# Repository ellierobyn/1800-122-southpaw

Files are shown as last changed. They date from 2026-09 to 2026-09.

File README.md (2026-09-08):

# 1800-122 Southpaw Keyboard [WIP]
A bigger than full size keyboard with the arrow keys compressed into the alphas like a 1800 and the number pad on the left (southpaw). Takes inspiration in name and form from the famous IBM Model F122.

1800-122 SP LAYOUT

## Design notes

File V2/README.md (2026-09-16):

# 1800-122 Southpaw V2
This version of the board is the actively in development version using local repos and generally better best practices.

NOTE: The footprints used in the 122-LIB "SW_Hotswap_Kailh_MX_1.00u_**PnP**" & "SW_Hotswap_Kailh_MX_Plated_1.00u_**PnP**" are forked from the official KiCad key switch repo. Positionally they are the same to "SW_Hotswap_Kailh_MX_1.00u" & "SW_Hotswap_Kailh_MX_Plated_1.00u" **EXCEPT** their component origin is located in the same place as JLCPCB's PN C41430893 so the manufacturing files exported are compatible with their Pick and Place machines for automated PCB assembly. The 2 locating pin holes also had their nominal sizes shrunk by .001" to accommodate JLCPCB's capabilities.

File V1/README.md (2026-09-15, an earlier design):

# NOTICE: DEPRECATED

This version of the PCB utilized ai03's deprecated MX Keyswitch Libraries, a random RP2040 lib and a random W25Q128JVSIQ lib. I don't recommend using this PCB as a finished project but may be a helpful reference. This PCB was never manufactured so there are also probably DRC errors.

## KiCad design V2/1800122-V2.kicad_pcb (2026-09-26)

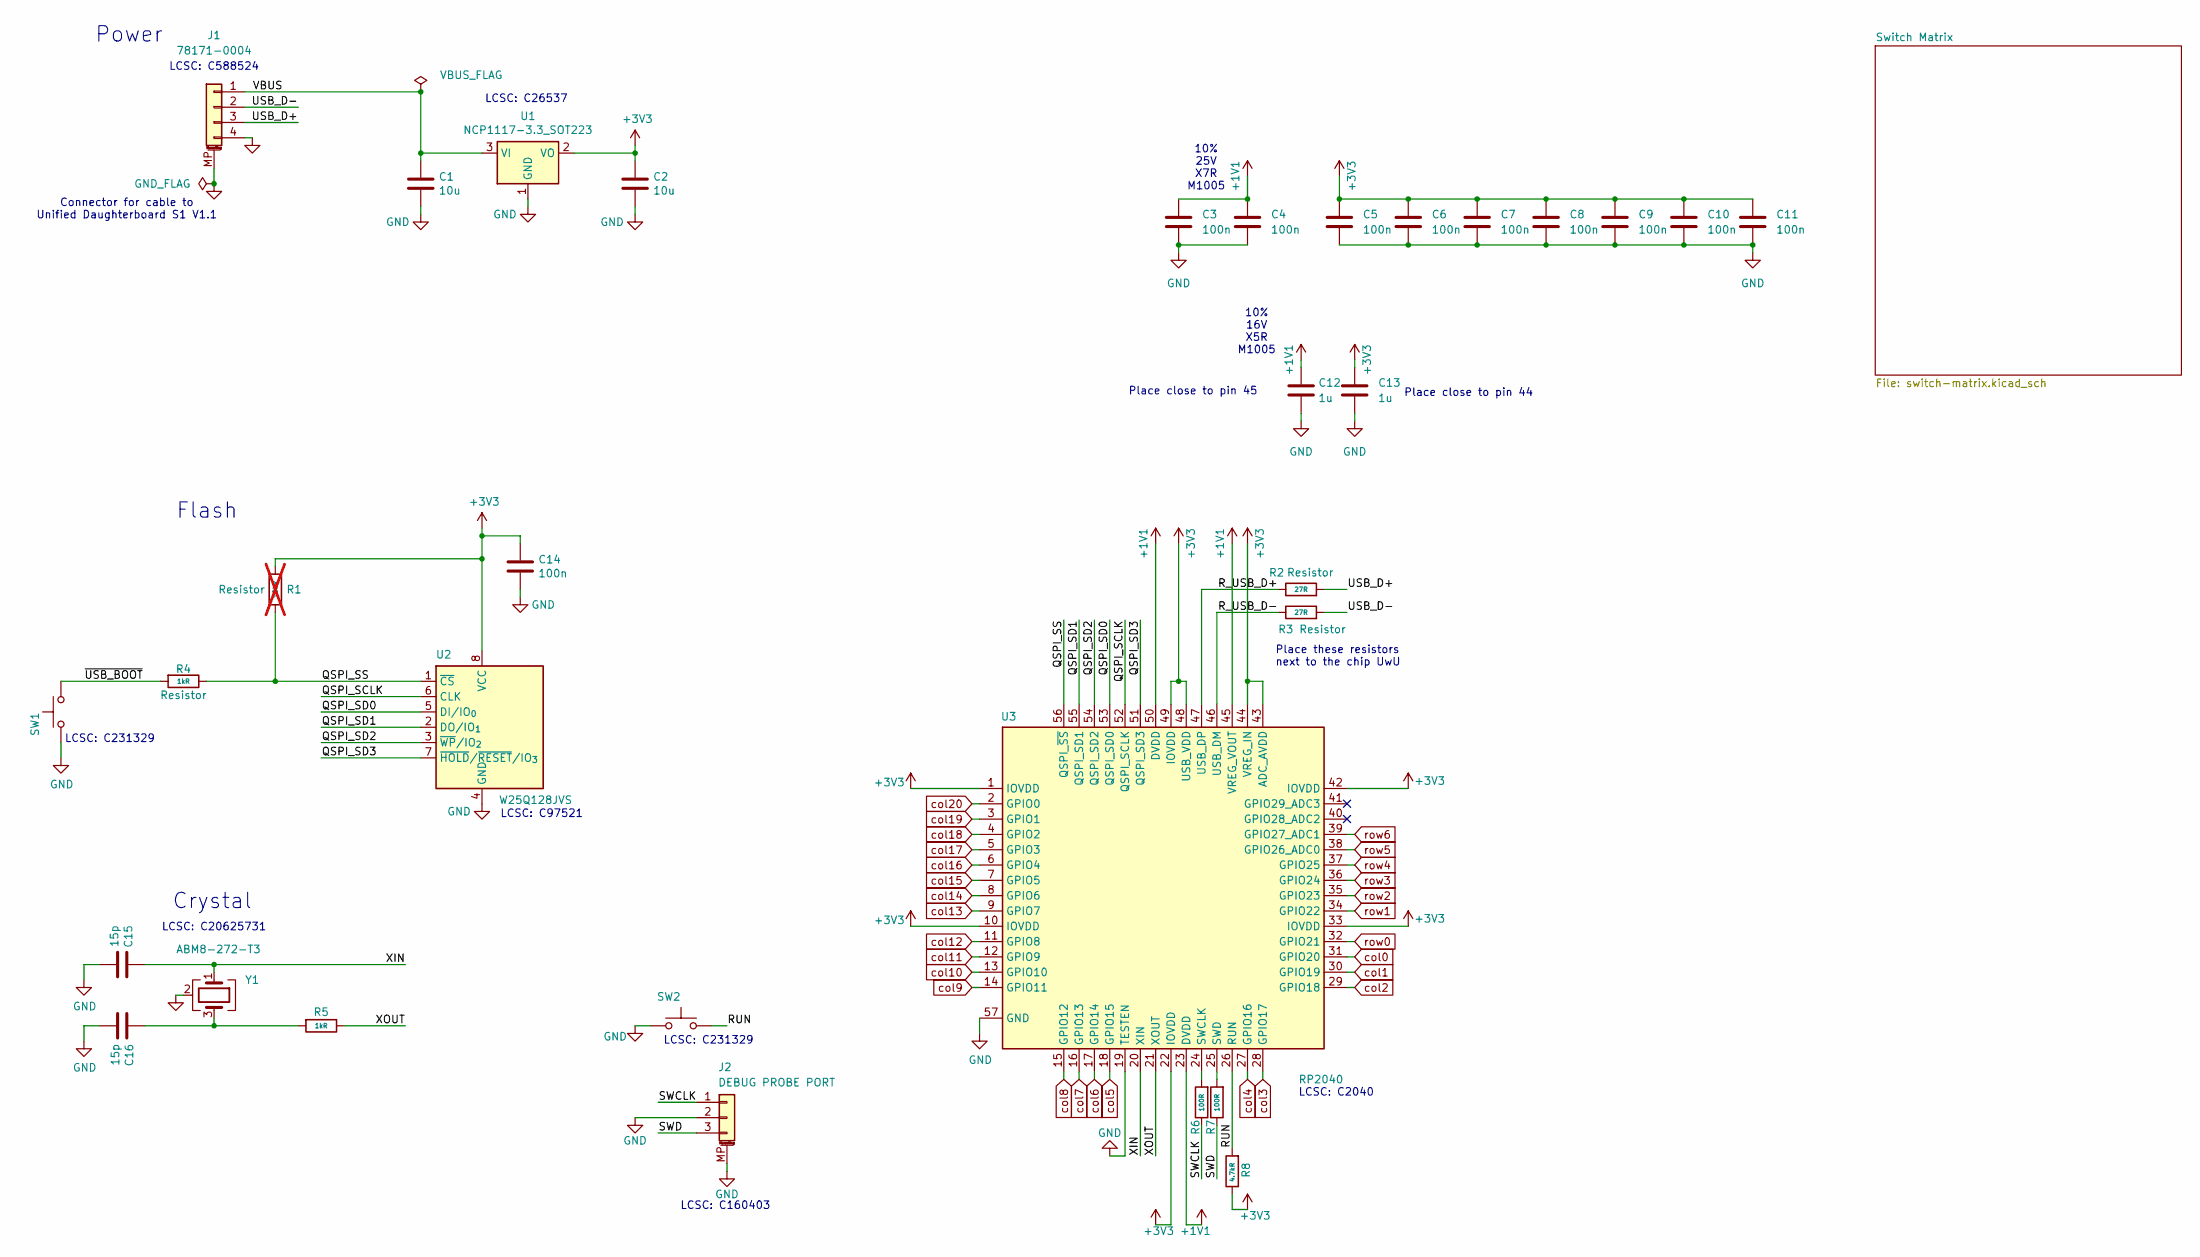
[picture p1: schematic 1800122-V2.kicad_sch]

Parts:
C1, C2: 10u; C_0402_1005Metric-JLCSILK
C3, C4, C5, C6, C7, C8, C9, C10, C11, C14: 100n; C_0402_1005Metric-JLCSILK
C12, C13: 1u; C_0402_1005Metric-JLCSILK
C15, C16: 15p; C_0402_1005Metric-JLCSILK
J1: 78171-0004; PicoEZMate-Reinforced-Lite; Manufacturer Part Number 78171-0004; LCSC Part Number C588524
J2: DEBUG PROBE PORT; JST_SH_SM03B-SRSS-TB_1x03-1MP_P1.00mm_Horizontal; LCSC Part Number C160403
R1: 10kR; R_0402_1005Metric-JLCSILK; not fitted
R2, R3: 27R; R_0402_1005Metric-JLCSILK
R4, R5: 1kR; R_0402_1005Metric-JLCSILK
R6, R7: 100R; R_0402_1005Metric-JLCSILK
R8: 4.7kR; R_0402_1005Metric-JLCSILK
SW1: BOOTSEL; SW_SPST_B3U-1000P; LCSC Part Number C231329
SW2: RESET; SW_SPST_B3U-1000P; LCSC Part Number C231329
U1: NCP1117-3.3_SOT223; SOT-223-3_TabPin2; LCSC Part Number C26537
U2: W25Q128JVS; SOIC-8_5.3x5.3mm_P1.27mm; LCSC Part Number C97521
U3: RP2040; part_uid RP-01EKHS-ZTKTEH; LCSC Part Number C2040
Y1: ABM8-272-T3; Crystal_SMD_3225-4Pin_3.2x2.5mm; LCSC Part Number C20625731

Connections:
+1V1: C3.1, C4.1, C12.1, U3.23 (DVDD), U3.45 (VREG_VOUT), U3.50 (DVDD)
+3V3: C2.1, C5.1, C6.1, C7.1, C8.1, C9.1, C10.1, C11.1, C13.1, C14.1, R1.1, R8.1, U1.2 (VO), U2.8 (VCC), U3.1 (IOVDD), U3.10 (IOVDD), U3.22 (IOVDD), U3.33 (IOVDD), U3.42 (IOVDD), U3.43 (ADC_AVDD), U3.44 (VREG_IN), U3.48 (USB_VDD), U3.49 (IOVDD)
/QSPI_SCLK: U2.6 (CLK), U3.52 (QSPI_SCLK)
/QSPI_SD0: U2.5 (DI/IO_{0}), U3.53 (QSPI_SD0)
/QSPI_SD1: U2.2 (DO/IO_{1}), U3.55 (QSPI_SD1)
/QSPI_SD2: U2.3 (~WP/IO_{2}), U3.54 (QSPI_SD2)
/QSPI_SD3: U2.7 (~HOLD/~RESET/IO_{3}), U3.51 (QSPI_SD3)
/QSPI_SS: R1.2, R4.1, U2.1 (~CS), U3.56 (QSPI_~SS)
/RUN: R8.2, SW2.2, U3.26 (RUN)
/R_USB_D+: R2.1, U3.47 (USB_DP)
/R_USB_D-: R3.1, U3.46 (USB_DM)
/SWCLK: J2.1, R6.1
/SWD: J2.3, R7.1
/USB_D+: J1.3, R2.2
/USB_D-: J1.2, R3.2
/VBUS: C1.1, J1.1, U1.3 (VI)
/XIN: C15.1, U3.20 (XIN), Y1.1
/XOUT: R5.1, U3.21 (XOUT)
/~USB_BOOT: R4.2, SW1.2
GND: C1.2, C2.2, C3.2, C4.2, C5.2, C6.2, C7.2, C8.2, C9.2, C10.2, C11.2, C12.2, C13.2, C14.2, C15.2, C16.2, J1.4, J1.MP (MountPin), J2.2, J2.MP (MountPin), SW1.1, SW2.1, U1.1 (GND), U2.4 (GND), U3.19 (TESTEN), U3.57 (GND), Y1.2 (G), Y1.4 (G)
unnamed: C16.1, R5.2, Y1.3
unnamed: R6.2, U3.24 (SWCLK)
unnamed: R7.2, U3.25 (SWD)
col0: U3.31 (GPIO20); also elsewhere on the board
col1: U3.30 (GPIO19); also elsewhere on the board
col2: U3.29 (GPIO18); also elsewhere on the board
col3: U3.28 (GPIO17); also elsewhere on the board
col4: U3.27 (GPIO16); also elsewhere on the board
col5: U3.18 (GPIO15); also elsewhere on the board
col6: U3.17 (GPIO14); also elsewhere on the board
col7: U3.16 (GPIO13); also elsewhere on the board
col8: U3.15 (GPIO12); also elsewhere on the board
col9: U3.14 (GPIO11); also elsewhere on the board
col10: U3.13 (GPIO10); also elsewhere on the board
col11: U3.12 (GPIO9); also elsewhere on the board
col12: U3.11 (GPIO8); also elsewhere on the board
col13: U3.9 (GPIO7); also elsewhere on the board
col14: U3.8 (GPIO6); also elsewhere on the board
col15: U3.7 (GPIO5); also elsewhere on the board
col16: U3.6 (GPIO4); also elsewhere on the board
col17: U3.5 (GPIO3); also elsewhere on the board
col18: U3.4 (GPIO2); also elsewhere on the board
col19: U3.3 (GPIO1); also elsewhere on the board
col20: U3.2 (GPIO0); also elsewhere on the board
row0: U3.32 (GPIO21); also elsewhere on the board
row1: U3.34 (GPIO22); also elsewhere on the board
row2: U3.35 (GPIO23); also elsewhere on the board
row3: U3.36 (GPIO24); also elsewhere on the board
row4: U3.37 (GPIO25); also elsewhere on the board
row5: U3.38 (GPIO26_ADC0); also elsewhere on the board
row6: U3.39 (GPIO27_ADC1); also elsewhere on the board

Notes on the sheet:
LCSC: C2040
LCSC: C20625731
LCSC: C26537
Power
Crystal
LCSC: C97521
Place close to pin 45
LCSC: C231329
Connector for cable to Unified Daughterboard S1 V1.1
10% 16V X5R M1005
LCSC: C160403
10% 25V X7R M1005
Place close to pin 44
LCSC: C588524
Place these resistors next to the chip UwU
Flash

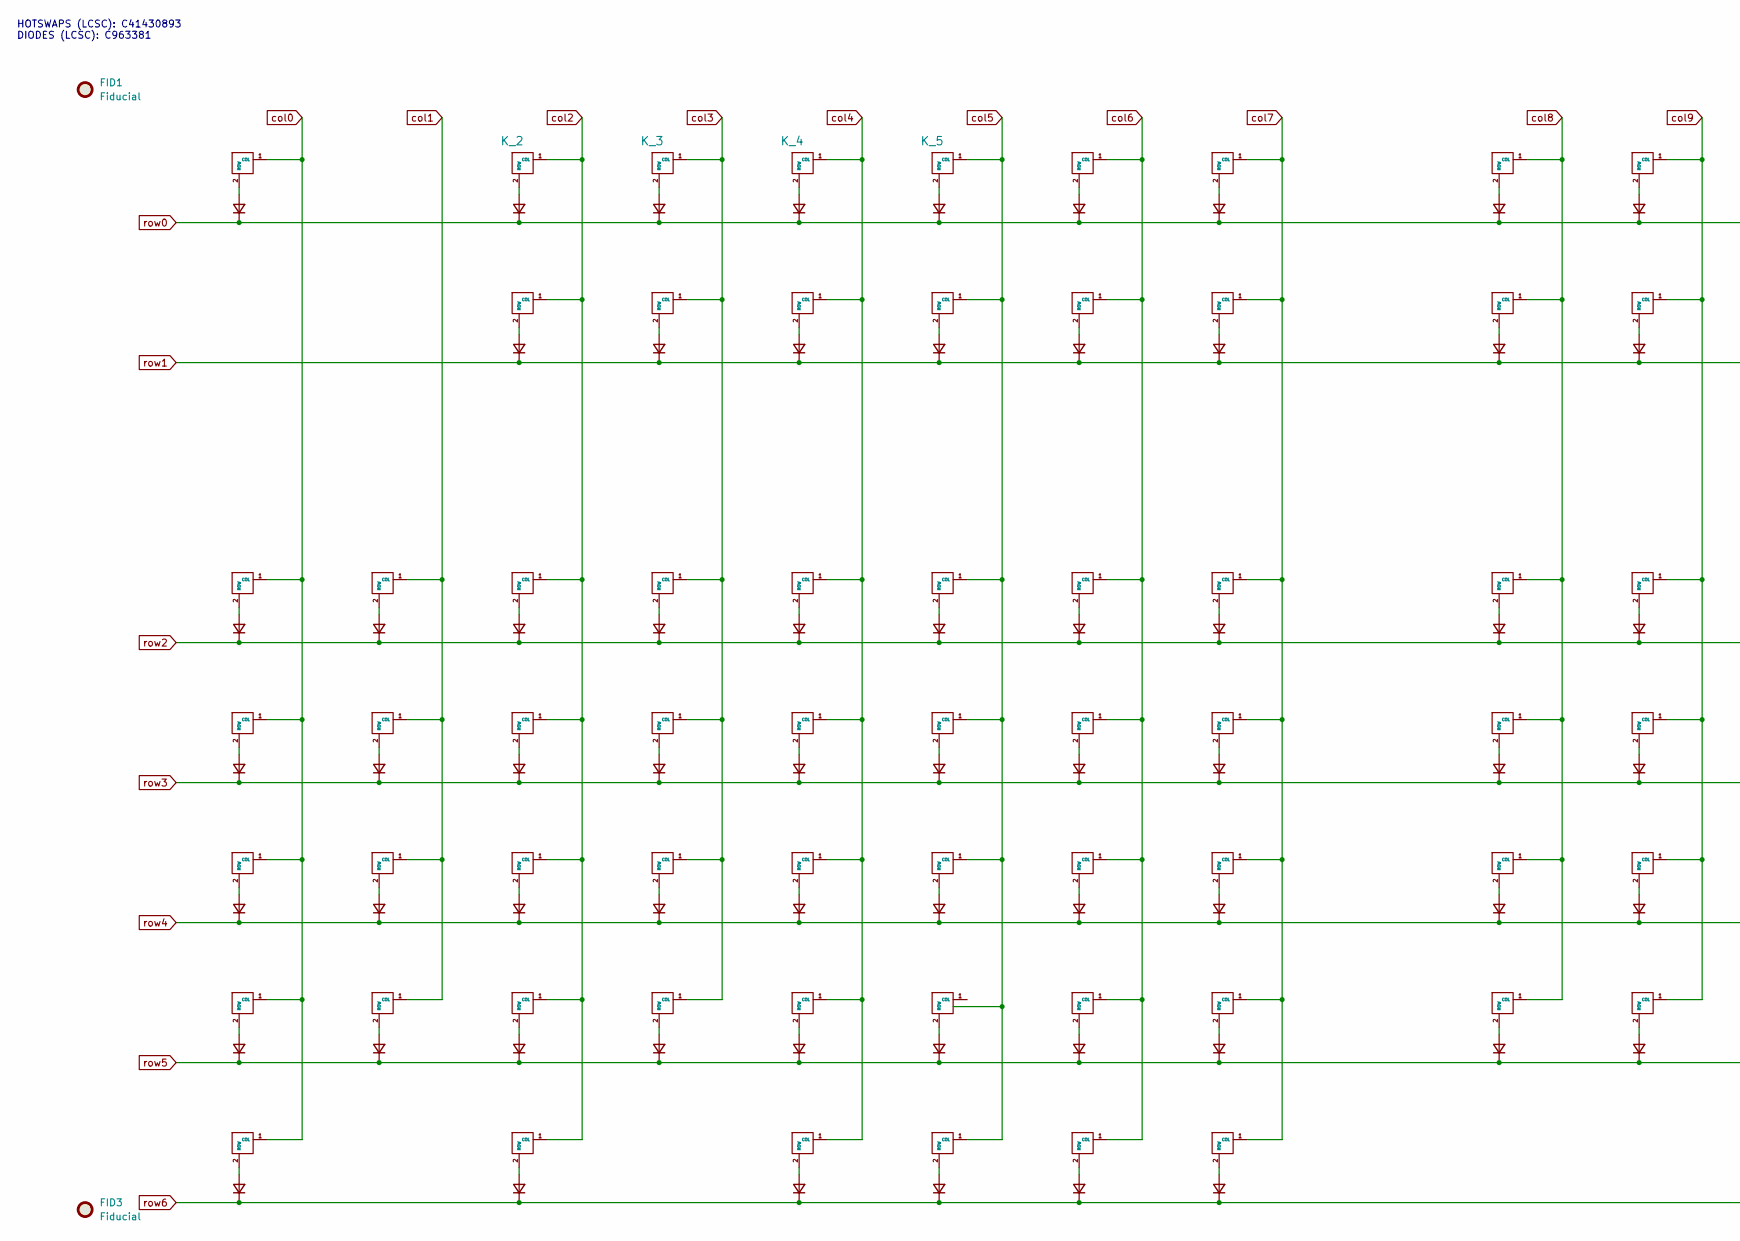
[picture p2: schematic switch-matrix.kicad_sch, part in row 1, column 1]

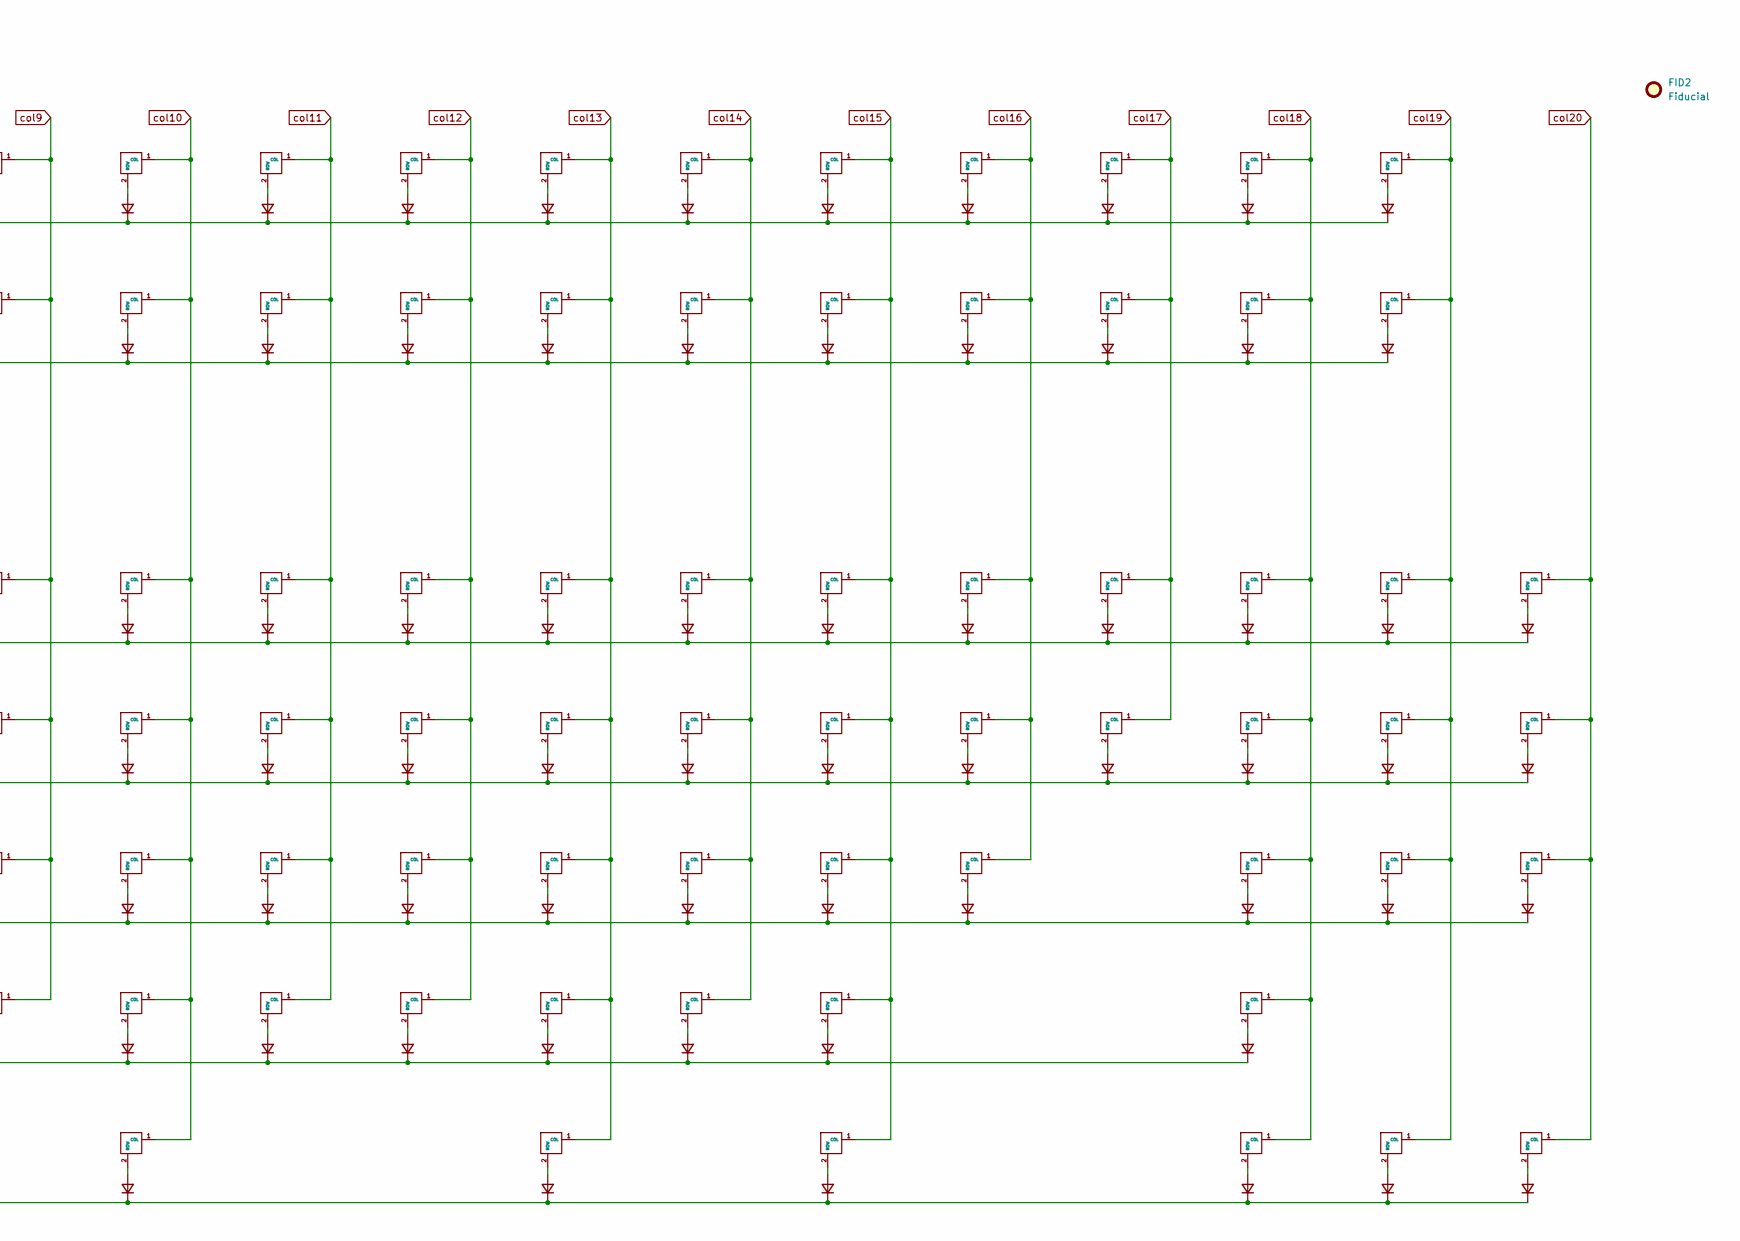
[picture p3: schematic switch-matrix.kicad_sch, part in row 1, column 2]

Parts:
D_1, D_2, D_3, D_4, D_5, D_6, D_7, D_8, D_9, D_10, D_11, D_12, D_13, D_14, D_15, D_16, D_17, D_18, D_19, D_20, D_21, D_22, D_23, D_24, D_25, D_26, D_27, D_28, D_29, D_30, D_31, D_32, D_33, D_34, D_35, D_36, D_37, D_38, D_39, D_40, D_41, D_42, D_43, D_44, D_45, D_46, D_47, D_48, D_49, D_50, D_51, D_52, D_53, D_54, D_55, D_56, D_57, D_58, D_59, D_60, D_61, D_62, D_63, D_64, D_65, D_66, D_67, D_68, D_69, D_70, D_71, D_72, D_73, D_74, D_75, D_76, D_77, D_78, D_79, D_80, D_81, D_82, D_83, D_84, D_85, D_86, D_87, D_88, D_89, D_90, D_91, D_92, D_93, D_94, D_95, D_96, D_97, D_98, D_99, D_100, D_101, D_102, D_103, D_104, D_105, D_106, D_107, D_108, D_109, D_110, D_111, D_112, D_113, D_114, D_115, D_116, D_117, D_118, D_119, D_120, D_121, D_122, D_123, D_124, D_125, D_126, D_127, D_128: D; D_SOD-123; LCSC Part Number C963381
FID1, FID2, FID3: Fiducial; Fiducial_1mm_Mask2mm
K_1, K_2, K_3, K_4, K_5, K_6, K_7, K_8, K_9, K_10, K_11, K_12, K_13, K_14, K_15, K_16, K_17, K_18, K_19, K_20, K_21, K_22, K_23, K_24, K_25, K_26, K_27, K_28, K_29, K_30, K_31, K_32, K_33, K_34, K_35, K_36, K_37, K_38, K_39, K_40, K_41, K_42, K_43, K_44, K_45, K_46, K_47, K_48, K_49, K_50, K_51, K_52, K_53, K_54, K_55, K_56, K_57, K_58, K_59, K_60, K_61, K_62, K_63, K_64, K_65, K_66, K_67, K_68, K_69, K_70, K_71, K_72, K_73, K_74, K_75, K_76, K_77, K_78, K_79, K_80, K_81, K_82, K_83, K_84, K_85, K_86, K_87, K_88, K_89, K_90, K_91, K_92, K_93, K_94, K_95, K_96, K_97, K_98, K_99, K_100, K_101, K_102, K_103, K_104, K_105, K_106, K_107, K_108, K_109, K_110, K_111, K_112, K_113, K_114, K_115, K_116, K_117, K_118, K_119, K_120, K_121, K_122, K_123, K_124, K_125, K_126, K_127, K_128: KEYSW; SW_Hotswap_Kailh_MX_Plated_1.00u_PnP; LCSC Part Number C41430893

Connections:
unnamed: D_1.2 (A), K_1.2 (ROW)
unnamed: D_2.2 (A), K_2.2 (ROW)
unnamed: D_3.2 (A), K_3.2 (ROW)
unnamed: D_4.2 (A), K_4.2 (ROW)
unnamed: D_5.2 (A), K_5.2 (ROW)
unnamed: D_6.2 (A), K_6.2 (ROW)
unnamed: D_7.2 (A), K_7.2 (ROW)
unnamed: D_8.2 (A), K_8.2 (ROW)
unnamed: D_9.2 (A), K_9.2 (ROW)
unnamed: D_10.2 (A), K_10.2 (ROW)
unnamed: D_11.2 (A), K_11.2 (ROW)
unnamed: D_12.2 (A), K_12.2 (ROW)
unnamed: D_13.2 (A), K_13.2 (ROW)
unnamed: D_14.2 (A), K_14.2 (ROW)
unnamed: D_15.2 (A), K_15.2 (ROW)
unnamed: D_16.2 (A), K_16.2 (ROW)
unnamed: D_17.2 (A), K_17.2 (ROW)
unnamed: D_18.2 (A), K_18.2 (ROW)
unnamed: D_19.2 (A), K_19.2 (ROW)
unnamed: D_20.2 (A), K_20.2 (ROW)
unnamed: D_21.2 (A), K_21.2 (ROW)
unnamed: D_22.2 (A), K_22.2 (ROW)
unnamed: D_23.2 (A), K_23.2 (ROW)
unnamed: D_24.2 (A), K_24.2 (ROW)
unnamed: D_25.2 (A), K_25.2 (ROW)
unnamed: D_26.2 (A), K_26.2 (ROW)
unnamed: D_27.2 (A), K_27.2 (ROW)
unnamed: D_28.2 (A), K_28.2 (ROW)
unnamed: D_29.2 (A), K_29.2 (ROW)
unnamed: D_30.2 (A), K_30.2 (ROW)
unnamed: D_31.2 (A), K_31.2 (ROW)
unnamed: D_32.2 (A), K_32.2 (ROW)
unnamed: D_33.2 (A), K_33.2 (ROW)
unnamed: D_34.2 (A), K_34.2 (ROW)
unnamed: D_35.2 (A), K_35.2 (ROW)
unnamed: D_36.2 (A), K_36.2 (ROW)
unnamed: D_37.2 (A), K_37.2 (ROW)
unnamed: D_38.2 (A), K_38.2 (ROW)
unnamed: D_39.2 (A), K_39.2 (ROW)
unnamed: D_40.2 (A), K_40.2 (ROW)
unnamed: D_41.2 (A), K_41.2 (ROW)
unnamed: D_42.2 (A), K_42.2 (ROW)
unnamed: D_43.2 (A), K_43.2 (ROW)
unnamed: D_44.2 (A), K_44.2 (ROW)
unnamed: D_45.2 (A), K_45.2 (ROW)
unnamed: D_46.2 (A), K_46.2 (ROW)
unnamed: D_47.2 (A), K_47.2 (ROW)
unnamed: D_48.2 (A), K_48.2 (ROW)
unnamed: D_49.2 (A), K_49.2 (ROW)
unnamed: D_50.2 (A), K_50.2 (ROW)
unnamed: D_51.2 (A), K_51.2 (ROW)
unnamed: D_52.2 (A), K_52.2 (ROW)
unnamed: D_53.2 (A), K_53.2 (ROW)
unnamed: D_54.2 (A), K_54.2 (ROW)
unnamed: D_55.2 (A), K_55.2 (ROW)
unnamed: D_56.2 (A), K_56.2 (ROW)
unnamed: D_57.2 (A), K_57.2 (ROW)
unnamed: D_58.2 (A), K_58.2 (ROW)
unnamed: D_59.2 (A), K_59.2 (ROW)
unnamed: D_60.2 (A), K_60.2 (ROW)
unnamed: D_61.2 (A), K_61.2 (ROW)
unnamed: D_62.2 (A), K_62.2 (ROW)
unnamed: D_63.2 (A), K_63.2 (ROW)
unnamed: D_64.2 (A), K_64.2 (ROW)
unnamed: D_65.2 (A), K_65.2 (ROW)
unnamed: D_66.2 (A), K_66.2 (ROW)
unnamed: D_67.2 (A), K_67.2 (ROW)
unnamed: D_68.2 (A), K_68.2 (ROW)
unnamed: D_69.2 (A), K_69.2 (ROW)
unnamed: D_70.2 (A), K_70.2 (ROW)
unnamed: D_71.2 (A), K_71.2 (ROW)
unnamed: D_72.2 (A), K_72.2 (ROW)
unnamed: D_73.2 (A), K_73.2 (ROW)
unnamed: D_74.2 (A), K_74.2 (ROW)
unnamed: D_75.2 (A), K_75.2 (ROW)
unnamed: D_76.2 (A), K_76.2 (ROW)
unnamed: D_77.2 (A), K_77.2 (ROW)
unnamed: D_78.2 (A), K_78.2 (ROW)
unnamed: D_79.2 (A), K_79.2 (ROW)
unnamed: D_80.2 (A), K_80.2 (ROW)
unnamed: D_81.2 (A), K_81.2 (ROW)
unnamed: D_82.2 (A), K_82.2 (ROW)
unnamed: D_83.2 (A), K_83.2 (ROW)
unnamed: D_84.2 (A), K_84.2 (ROW)
unnamed: D_85.2 (A), K_85.2 (ROW)
unnamed: D_86.2 (A), K_86.2 (ROW)
unnamed: D_87.2 (A), K_87.2 (ROW)
unnamed: D_88.2 (A), K_88.2 (ROW)
unnamed: D_89.2 (A), K_89.2 (ROW)
unnamed: D_90.2 (A), K_90.2 (ROW)
unnamed: D_91.2 (A), K_91.2 (ROW)
unnamed: D_92.2 (A), K_92.2 (ROW)
unnamed: D_93.2 (A), K_93.2 (ROW)
unnamed: D_94.2 (A), K_94.2 (ROW)
unnamed: D_95.2 (A), K_95.2 (ROW)
unnamed: D_96.2 (A), K_96.2 (ROW)
unnamed: D_97.2 (A), K_97.2 (ROW)
unnamed: D_98.2 (A), K_98.2 (ROW)
unnamed: D_99.2 (A), K_99.2 (ROW)
unnamed: D_100.2 (A), K_100.2 (ROW)
unnamed: D_101.2 (A), K_101.2 (ROW)
unnamed: D_102.2 (A), K_102.2 (ROW)
unnamed: D_103.2 (A), K_103.2 (ROW)
unnamed: D_104.2 (A), K_104.2 (ROW)
unnamed: D_105.2 (A), K_105.2 (ROW_2)
unnamed: D_106.2 (A), K_106.2 (ROW)
unnamed: D_107.2 (A), K_107.2 (ROW)
unnamed: D_108.2 (A), K_108.2 (ROW)
unnamed: D_109.2 (A), K_109.2 (ROW)
unnamed: D_110.2 (A), K_110.2 (ROW)
unnamed: D_111.2 (A), K_111.2 (ROW)
unnamed: D_112.2 (A), K_112.2 (ROW)
unnamed: D_113.2 (A), K_113.2 (ROW)
unnamed: D_114.2 (A), K_114.2 (ROW)
unnamed: D_115.2 (A), K_115.2 (ROW)
unnamed: D_116.2 (A), K_116.2 (ROW)
unnamed: D_117.2 (A), K_117.2 (ROW)
unnamed: D_118.2 (A), K_118.2 (ROW)
unnamed: D_119.2 (A), K_119.2 (ROW)
unnamed: D_120.2 (A), K_120.2 (ROW)
unnamed: D_121.2 (A), K_121.2 (ROW)
unnamed: D_122.2 (A), K_122.2 (ROW)
unnamed: D_123.2 (A), K_123.2 (ROW)
unnamed: D_124.2 (A), K_124.2 (ROW)
unnamed: D_125.2 (A), K_125.2 (ROW)
unnamed: D_126.2 (A), K_126.2 (ROW)
unnamed: D_127.2 (A), K_127.2 (ROW)
unnamed: D_128.2 (A), K_128.2 (ROW)
col0: K_1.1 (COL), K_38.1 (COL), K_59.1 (COL), K_80.1 (COL), K_100.1 (COL), K_117.1 (COL); also elsewhere on the board
col1: K_39.1 (COL), K_60.1 (COL), K_81.1 (COL), K_101.1 (COL); also elsewhere on the board
col2: K_2.1 (COL), K_20.1 (COL), K_40.1 (COL), K_61.1 (COL), K_82.1 (COL), K_102.1 (COL), K_118.1 (COL); also elsewhere on the board
col3: K_3.1 (COL), K_21.1 (COL), K_41.1 (COL), K_62.1 (COL), K_83.1 (COL), K_103.1 (COL); also elsewhere on the board
col4: K_4.1 (COL), K_22.1 (COL), K_42.1 (COL), K_63.1 (COL), K_84.1 (COL), K_104.1 (COL), K_119.1 (COL); also elsewhere on the board
col5: K_5.1 (COL), K_23.1 (COL), K_43.1 (COL), K_64.1 (COL), K_85.1 (COL), K_120.1 (COL); also elsewhere on the board
col6: K_6.1 (COL), K_24.1 (COL), K_44.1 (COL), K_65.1 (COL), K_86.1 (COL), K_106.1 (COL), K_121.1 (COL); also elsewhere on the board
col7: K_7.1 (COL), K_25.1 (COL), K_45.1 (COL), K_66.1 (COL), K_87.1 (COL), K_107.1 (COL), K_122.1 (COL); also elsewhere on the board
col8: K_8.1 (COL), K_26.1 (COL), K_46.1 (COL), K_67.1 (COL), K_88.1 (COL), K_108.1 (COL); also elsewhere on the board
col9: K_9.1 (COL), K_27.1 (COL), K_47.1 (COL), K_68.1 (COL), K_89.1 (COL), K_109.1 (COL); also elsewhere on the board
col10: K_10.1 (COL), K_28.1 (COL), K_48.1 (COL), K_69.1 (COL), K_90.1 (COL), K_110.1 (COL), K_123.1 (COL); also elsewhere on the board
col11: K_11.1 (COL), K_29.1 (COL), K_49.1 (COL), K_70.1 (COL), K_91.1 (COL), K_111.1 (COL); also elsewhere on the board
col12: K_12.1 (COL), K_30.1 (COL), K_50.1 (COL), K_71.1 (COL), K_92.1 (COL), K_112.1 (COL); also elsewhere on the board
col13: K_13.1 (COL), K_31.1 (COL), K_51.1 (COL), K_72.1 (COL), K_93.1 (COL), K_113.1 (COL), K_124.1 (COL); also elsewhere on the board
col14: K_14.1 (COL), K_32.1 (COL), K_52.1 (COL), K_73.1 (COL), K_94.1 (COL), K_114.1 (COL); also elsewhere on the board
col15: K_15.1 (COL), K_33.1 (COL), K_53.1 (COL), K_74.1 (COL), K_95.1 (COL), K_115.1 (COL), K_125.1 (COL); also elsewhere on the board
col16: K_16.1 (COL), K_34.1 (COL), K_54.1 (COL), K_75.1 (COL), K_96.1 (COL); also elsewhere on the board
col17: K_17.1 (COL), K_35.1 (COL), K_55.1 (COL), K_76.1 (COL); also elsewhere on the board
col18: K_18.1 (COL), K_36.1 (COL), K_56.1 (COL), K_77.1 (COL), K_97.1 (COL), K_116.1 (COL), K_126.1 (COL); also elsewhere on the board
col19: K_19.1 (COL), K_37.1 (COL), K_57.1 (COL), K_78.1 (COL), K_98.1 (COL), K_127.1 (COL); also elsewhere on the board
col20: K_58.1 (COL), K_79.1 (COL), K_99.1 (COL), K_128.1 (COL); also elsewhere on the board
row0: D_1.1 (K), D_2.1 (K), D_3.1 (K), D_4.1 (K), D_5.1 (K), D_6.1 (K), D_7.1 (K), D_8.1 (K), D_9.1 (K), D_10.1 (K), D_11.1 (K), D_12.1 (K), D_13.1 (K), D_14.1 (K), D_15.1 (K), D_16.1 (K), D_17.1 (K), D_18.1 (K), D_19.1 (K); also elsewhere on the board
row1: D_20.1 (K), D_21.1 (K), D_22.1 (K), D_23.1 (K), D_24.1 (K), D_25.1 (K), D_26.1 (K), D_27.1 (K), D_28.1 (K), D_29.1 (K), D_30.1 (K), D_31.1 (K), D_32.1 (K), D_33.1 (K), D_34.1 (K), D_35.1 (K), D_36.1 (K), D_37.1 (K); also elsewhere on the board
row2: D_38.1 (K), D_39.1 (K), D_40.1 (K), D_41.1 (K), D_42.1 (K), D_43.1 (K), D_44.1 (K), D_45.1 (K), D_46.1 (K), D_47.1 (K), D_48.1 (K), D_49.1 (K), D_50.1 (K), D_51.1 (K), D_52.1 (K), D_53.1 (K), D_54.1 (K), D_55.1 (K), D_56.1 (K), D_57.1 (K), D_58.1 (K); also elsewhere on the board
row3: D_59.1 (K), D_60.1 (K), D_61.1 (K), D_62.1 (K), D_63.1 (K), D_64.1 (K), D_65.1 (K), D_66.1 (K), D_67.1 (K), D_68.1 (K), D_69.1 (K), D_70.1 (K), D_71.1 (K), D_72.1 (K), D_73.1 (K), D_74.1 (K), D_75.1 (K), D_76.1 (K), D_77.1 (K), D_78.1 (K), D_79.1 (K); also elsewhere on the board
row4: D_80.1 (K), D_81.1 (K), D_82.1 (K), D_83.1 (K), D_84.1 (K), D_85.1 (K), D_86.1 (K), D_87.1 (K), D_88.1 (K), D_89.1 (K), D_90.1 (K), D_91.1 (K), D_92.1 (K), D_93.1 (K), D_94.1 (K), D_95.1 (K), D_96.1 (K), D_97.1 (K), D_98.1 (K), D_99.1 (K); also elsewhere on the board
row5: D_100.1 (K), D_101.1 (K), D_102.1 (K), D_103.1 (K), D_104.1 (K), D_105.1 (K), D_106.1 (K), D_107.1 (K), D_108.1 (K), D_109.1 (K), D_110.1 (K), D_111.1 (K), D_112.1 (K), D_113.1 (K), D_114.1 (K), D_115.1 (K), D_116.1 (K); also elsewhere on the board
row6: D_117.1 (K), D_118.1 (K), D_119.1 (K), D_120.1 (K), D_121.1 (K), D_122.1 (K), D_123.1 (K), D_124.1 (K), D_125.1 (K), D_126.1 (K), D_127.1 (K), D_128.1 (K); also elsewhere on the board

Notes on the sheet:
HOTSWAPS (LCSC): C41430893 DIODES (LCSC): C963381

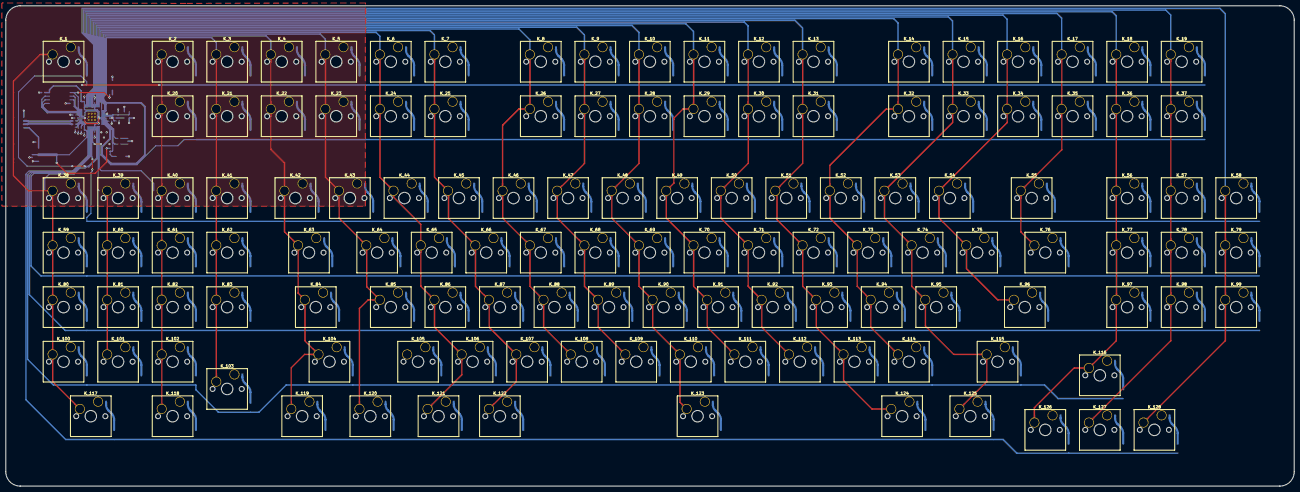
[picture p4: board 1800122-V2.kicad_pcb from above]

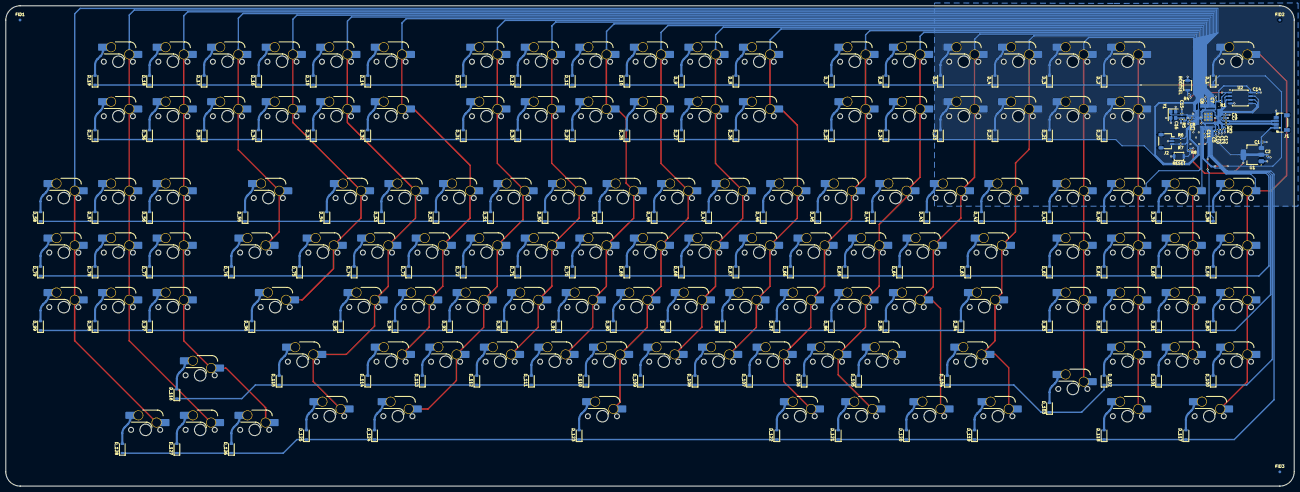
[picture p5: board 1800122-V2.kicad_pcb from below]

Board: 2 copper layers, 450.0 x 167.8 mm, 291 parts (163 on the bottom side), 179 nets.

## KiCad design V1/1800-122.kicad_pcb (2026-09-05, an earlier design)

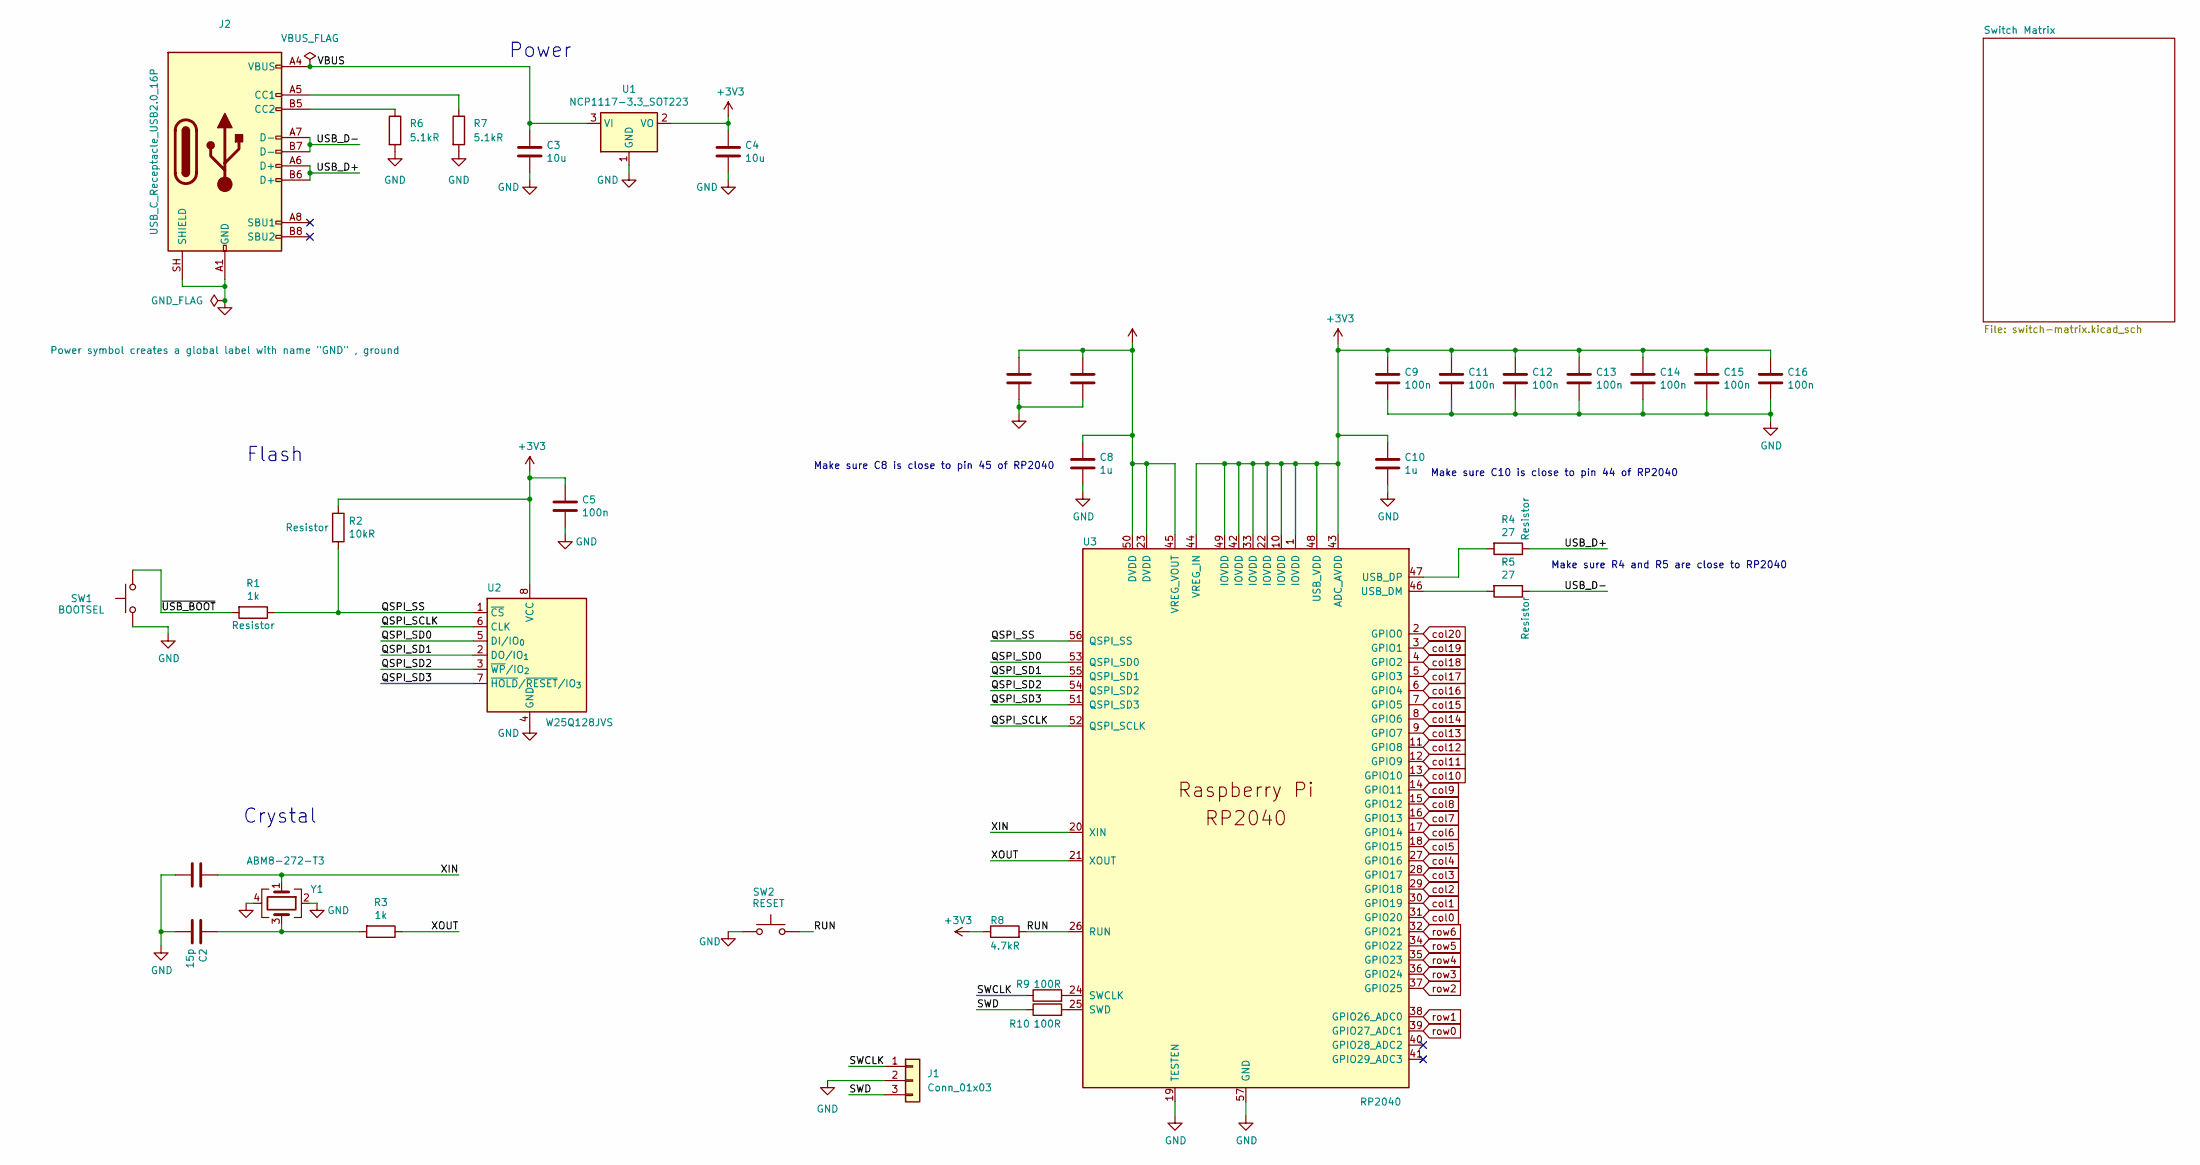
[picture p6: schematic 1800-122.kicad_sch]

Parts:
C1, C2: 15p; C_0402_1005Metric_Pad0.74x0.62mm_HandSolder
C3, C4: 10u; C_0402_1005Metric_Pad0.74x0.62mm_HandSolder
C5, C6, C7, C9, C11, C12, C13, C14, C15, C16: 100n; C_0402_1005Metric_Pad0.74x0.62mm_HandSolder
C8, C10: 1u; C_0402_1005Metric_Pad0.74x0.62mm_HandSolder
J1: Conn_01x03; JST_SH_SM03B-SRSS-TB_1x03-1MP_P1.00mm_Horizontal
J2: USB_C_Receptacle_USB2.0_16P; USB_C_Receptacle_GCT_USB4105-xx-A_16P_TopMnt_Horizontal
R1, R3: 1k; R_0402_1005Metric_Pad0.72x0.64mm_HandSolder
R2: 10kR; R_0402_1005Metric_Pad0.72x0.64mm_HandSolder
R4, R5: 27; R_0402_1005Metric_Pad0.72x0.64mm_HandSolder
R6, R7: 5.1kR; R_0402_1005Metric_Pad0.72x0.64mm_HandSolder
R8: 4.7kR; R_0402_1005Metric_Pad0.72x0.64mm_HandSolder
R9, R10: 100R; R_0402_1005Metric_Pad0.72x0.64mm_HandSolder
SW1: BOOTSEL; SW_SPST_PTS810
SW2: RESET; SW_SPST_PTS810
U1: NCP1117-3.3_SOT223; SOT-223-3_TabPin2
U2: W25Q128JVS; SOIC-8_5.3x5.3mm_P1.27mm
U3: RP2040; RP2040-QFN-56
Y1: ABM8-272-T3; Crystal_SMD_3225-4Pin_3.2x2.5mm

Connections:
+1V1: C6.1, C7.1, C8.1, U3.23 (DVDD), U3.45 (VREG_VOUT), U3.50 (DVDD)
+3V3: C4.1, C5.1, C9.1, C10.1, C11.1, C12.1, C13.1, C14.1, C15.1, C16.1, R2.1, R8.1, U1.2 (VO), U2.8 (VCC), U3.1 (IOVDD), U3.10 (IOVDD), U3.22 (IOVDD), U3.33 (IOVDD), U3.42 (IOVDD), U3.43 (ADC_AVDD), U3.44 (VREG_IN), U3.48 (USB_VDD), U3.49 (IOVDD)
/QSPI_SCLK: U2.6 (CLK), U3.52 (QSPI_SCLK)
/QSPI_SD0: U2.5 (DI/IO_{0}), U3.53 (QSPI_SD0)
/QSPI_SD1: U2.2 (DO/IO_{1}), U3.55 (QSPI_SD1)
/QSPI_SD2: U2.3 (~WP/IO_{2}), U3.54 (QSPI_SD2)
/QSPI_SD3: U2.7 (~HOLD/~RESET/IO_{3}), U3.51 (QSPI_SD3)
/QSPI_SS: R1.1, R2.2, U2.1 (~CS), U3.56 (QSPI_SS)
/RUN: R8.2, SW2.2, U3.26 (RUN)
/SWCLK: J1.1, R9.1
/SWD: J1.3, R10.1
/USB_D+: J2.A6 (D+), J2.B6 (D+), R4.1
/USB_D-: J2.A7 (D-), J2.B7 (D-), R5.1
/VBUS: C3.1, J2.A4 (VBUS), J2.A9 (VBUS), J2.B4 (VBUS), J2.B9 (VBUS), U1.3 (VI)
/XIN: C1.1, U3.20 (XIN), Y1.1
/XOUT: R3.1, U3.21 (XOUT)
/~USB_BOOT: R1.2, SW1.2
GND: C1.2, C2.2, C3.2, C4.2, C5.2, C6.2, C7.2, C8.2, C9.2, C10.2, C11.2, C12.2, C13.2, C14.2, C15.2, C16.2, J1.2, J2.A1 (GND), J2.A12 (GND), J2.B1 (GND), J2.B12 (GND), J2.SH (SHIELD), R6.2, R7.2, SW1.1, SW2.1, U1.1 (GND), U2.4 (GND), U3.19 (TESTEN), U3.57 (GND), Y1.2, Y1.4
unnamed: C2.1, R3.2, Y1.3
unnamed: J2.A5 (CC1), R7.1
unnamed: J2.B5 (CC2), R6.1
unnamed: R9.2, U3.24 (SWCLK)
unnamed: R10.2, U3.25 (SWD)
unnamed: R5.2, U3.46 (USB_DM)
unnamed: R4.2, U3.47 (USB_DP)
col0: U3.31 (GPIO20); also elsewhere on the board
col1: U3.30 (GPIO19); also elsewhere on the board
col2: U3.29 (GPIO18); also elsewhere on the board
col3: U3.28 (GPIO17); also elsewhere on the board
col4: U3.27 (GPIO16); also elsewhere on the board
col5: U3.18 (GPIO15); also elsewhere on the board
col6: U3.17 (GPIO14); also elsewhere on the board
col7: U3.16 (GPIO13); also elsewhere on the board
col8: U3.15 (GPIO12); also elsewhere on the board
col9: U3.14 (GPIO11); also elsewhere on the board
col10: U3.13 (GPIO10); also elsewhere on the board
col11: U3.12 (GPIO9); also elsewhere on the board
col12: U3.11 (GPIO8); also elsewhere on the board
col13: U3.9 (GPIO7); also elsewhere on the board
col14: U3.8 (GPIO6); also elsewhere on the board
col15: U3.7 (GPIO5); also elsewhere on the board
col16: U3.6 (GPIO4); also elsewhere on the board
col17: U3.5 (GPIO3); also elsewhere on the board
col18: U3.4 (GPIO2); also elsewhere on the board
col19: U3.3 (GPIO1); also elsewhere on the board
col20: U3.2 (GPIO0); also elsewhere on the board
row0: U3.39 (GPIO27_ADC1); also elsewhere on the board
row1: U3.38 (GPIO26_ADC0); also elsewhere on the board
row2: U3.37 (GPIO25); also elsewhere on the board
row3: U3.36 (GPIO24); also elsewhere on the board
row4: U3.35 (GPIO23); also elsewhere on the board
row5: U3.34 (GPIO22); also elsewhere on the board
row6: U3.32 (GPIO21); also elsewhere on the board

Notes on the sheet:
Power
Crystal
Make sure C8 is close to pin 45 of RP2040
Make sure C10 is close to pin 44 of RP2040
Make sure R4 and R5 are close to RP2040
Flash

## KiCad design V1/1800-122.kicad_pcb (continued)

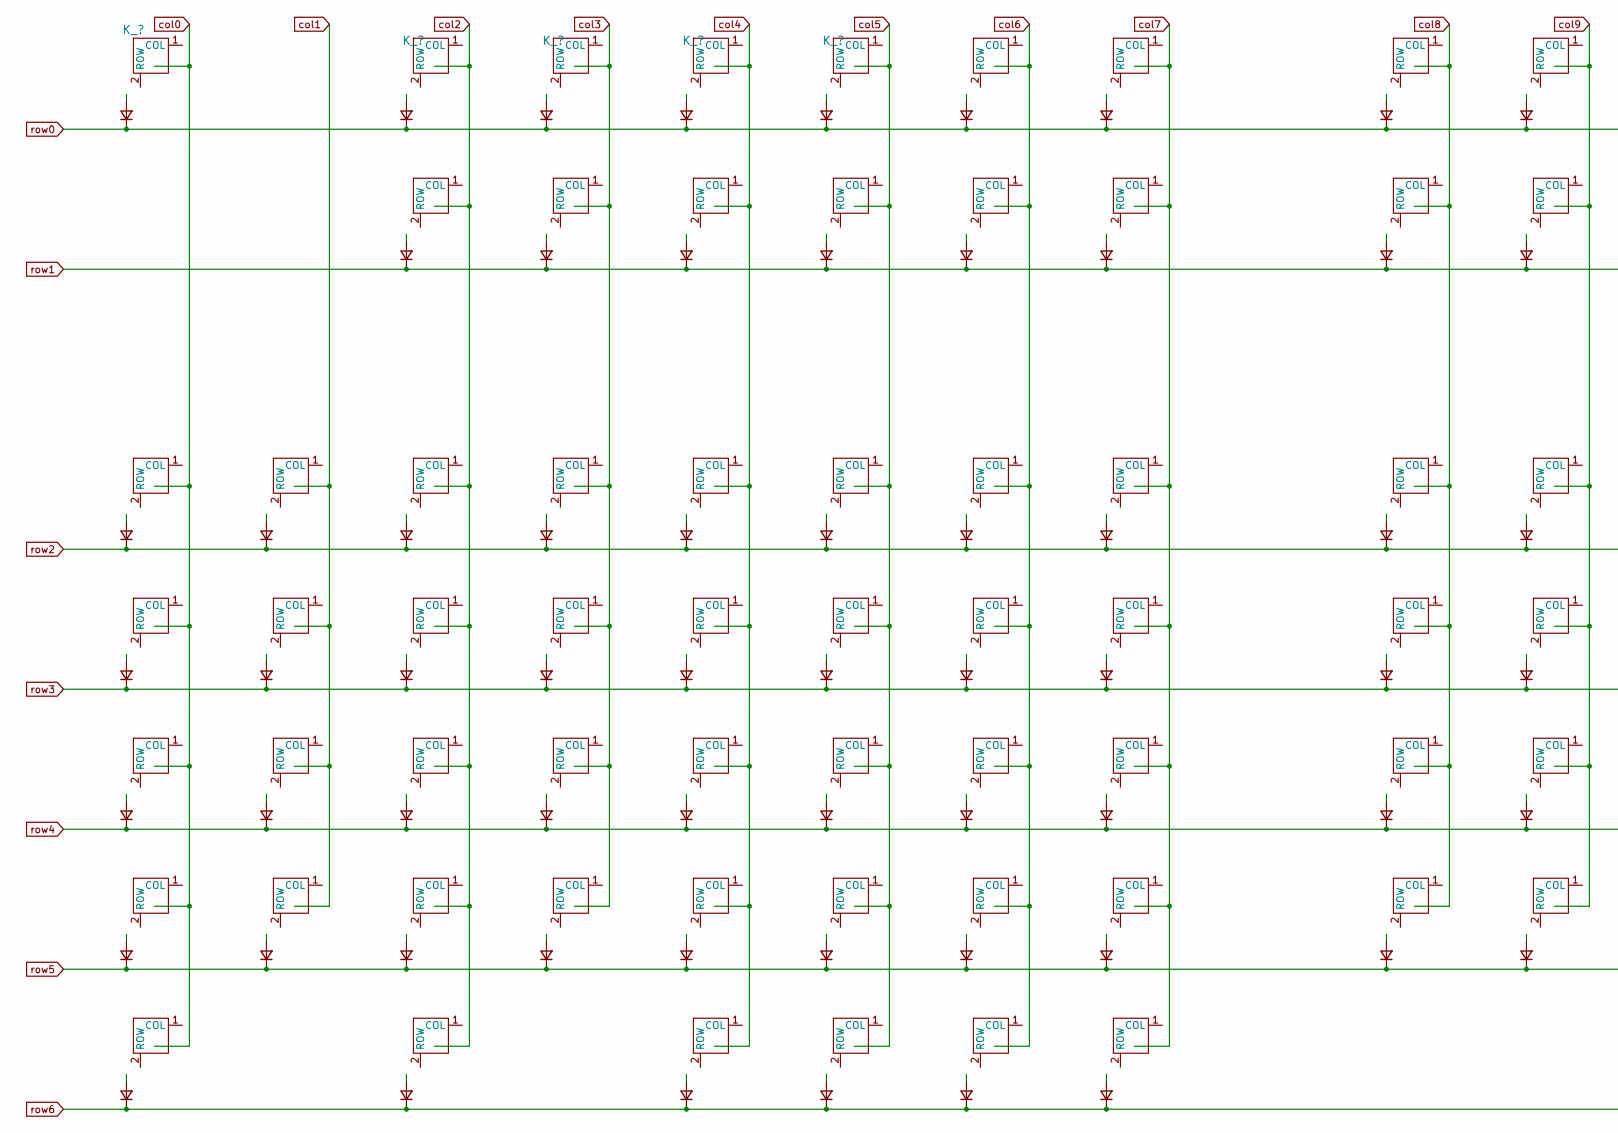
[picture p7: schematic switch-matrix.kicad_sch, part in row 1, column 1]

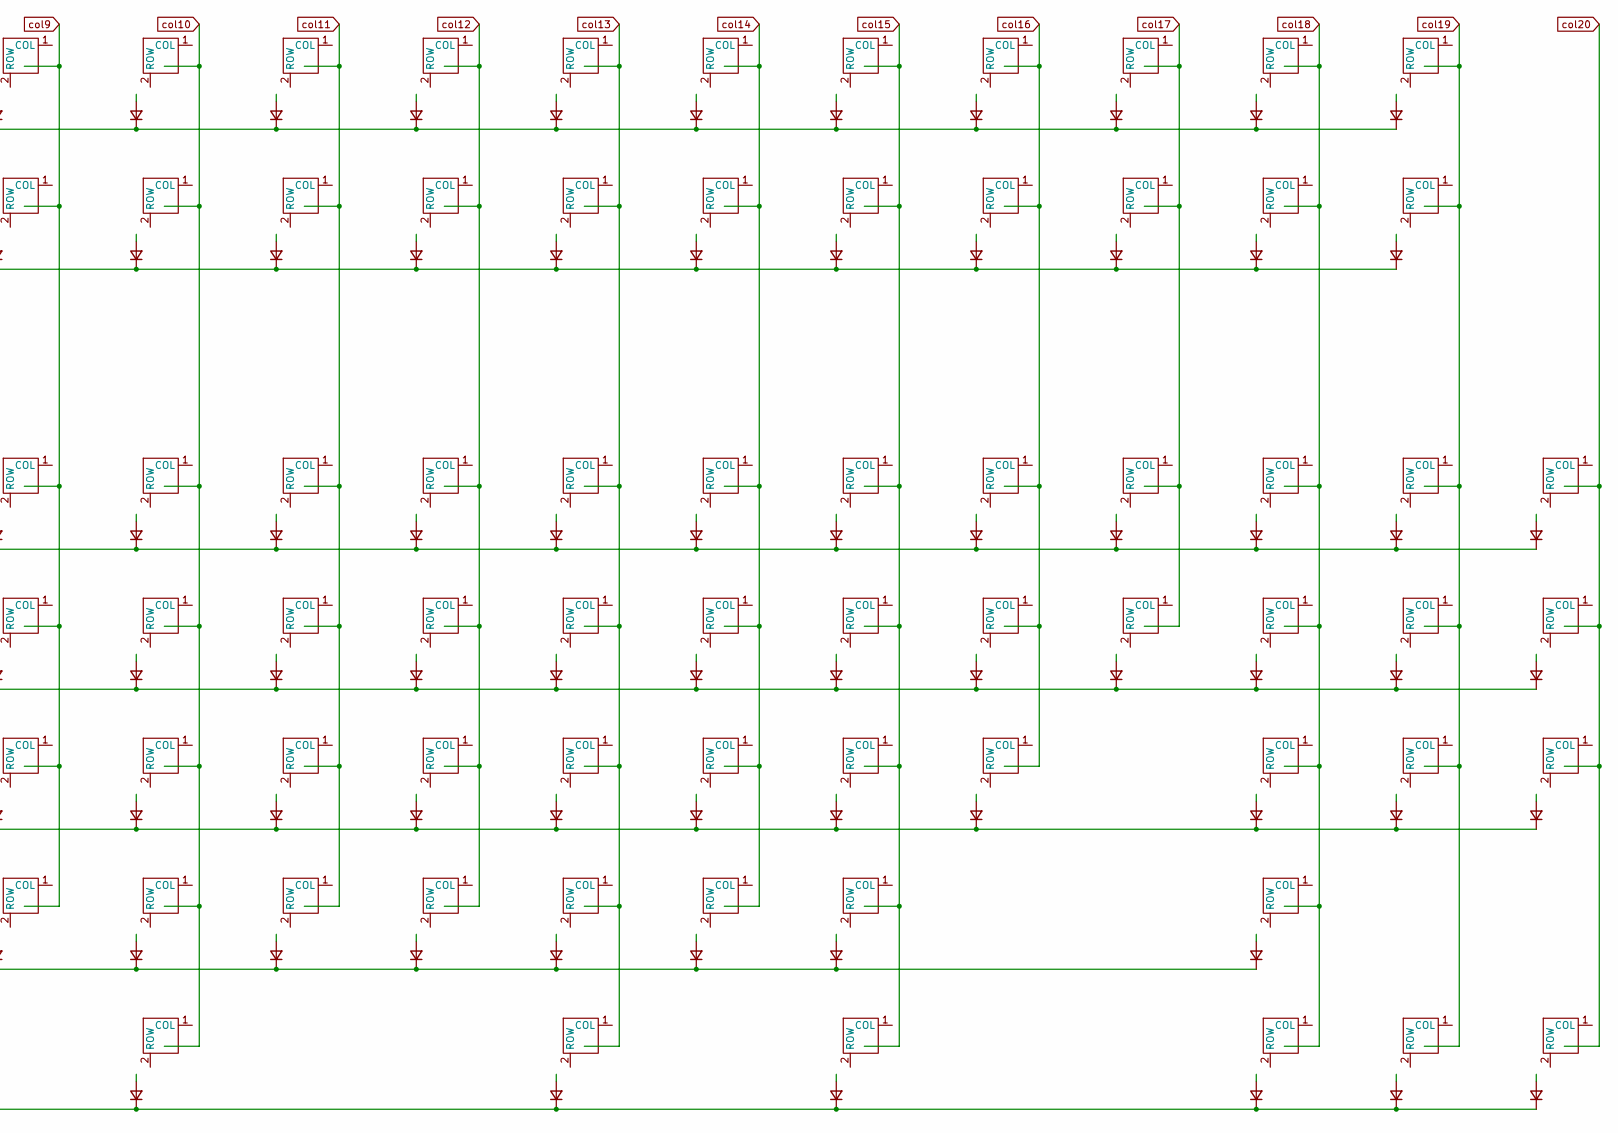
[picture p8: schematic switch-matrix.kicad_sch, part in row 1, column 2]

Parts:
D1, D2, D3, D4, D5, D6, D7, D8, D9, D10, D11, D12, D13, D14, D15, D16, D17, D18, D19, D20, D21, D22, D23, D24, D25, D26, D27, D28, D29, D30, D31, D32, D33, D34, D35, D36, D37, D38, D39, D40, D41, D42, D43, D44, D45, D46, D47, D48, D49, D50, D51, D52, D53, D54, D55, D56, D57, D58, D59, D60, D61, D62, D63, D64, D65, D66, D67, D68, D69, D70, D71, D72, D73, D74, D75, D76, D77, D78, D79, D80, D81, D82, D83, D84, D85, D86, D87, D88, D89, D90, D91, D92, D93, D94, D95, D96, D97, D98, D99, D100, D101, D102, D103, D104, D105, D106, D107, D108, D109, D110, D111, D112, D113, D114, D115, D116, D117, D118, D119, D120, D121, D122, D123, D124, D125, D126, D127, D128: D; D_SOD-123
MX1, MX2, MX3, MX4, MX5, MX6, MX7, MX8, MX9, MX10, MX11, MX12, MX13, MX14, MX15, MX16, MX17, MX18, MX19, MX20, MX21, MX22, MX23, MX24, MX25, MX26, MX27, MX28, MX29, MX30, MX31, MX32, MX33, MX34, MX35, MX36, MX37, MX38, MX39, MX40, MX41, MX42, MX43, MX44, MX45, MX46, MX47, MX48, MX49, MX50, MX51, MX52, MX53, MX54, MX55, MX56, MX57, MX58, MX59, MX60, MX61, MX62, MX63, MX64, MX65, MX66, MX67, MX68, MX69, MX70, MX71, MX72, MX73, MX74, MX75, MX76, MX77, MX78, MX79, MX80, MX81, MX82, MX83, MX84, MX85, MX86, MX87, MX88, MX89, MX90, MX91, MX92, MX93, MX94, MX95, MX96, MX97, MX98, MX99, MX100, MX101, MX102, MX103, MX104, MX105, MX106, MX107, MX108, MX109, MX110, MX111, MX112, MX113, MX114, MX115, MX116, MX117, MX118, MX119, MX120, MX121, MX122, MX123, MX124, MX125, MX126, MX127, MX128: KEYSW; SW_Hotswap_Kailh_MX_1.00u

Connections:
unnamed: D1.2 (A), MX1.2 (ROW)
unnamed: D2.2 (A), MX2.2 (ROW)
unnamed: D3.2 (A), MX3.2 (ROW)
unnamed: D4.2 (A), MX4.2 (ROW)
unnamed: D5.2 (A), MX5.2 (ROW)
unnamed: D6.2 (A), MX6.2 (ROW)
unnamed: D7.2 (A), MX7.2 (ROW)
unnamed: D8.2 (A), MX8.2 (ROW)
unnamed: D9.2 (A), MX9.2 (ROW)
unnamed: D10.2 (A), MX10.2 (ROW)
unnamed: D11.2 (A), MX11.2 (ROW)
unnamed: D12.2 (A), MX12.2 (ROW)
unnamed: D13.2 (A), MX13.2 (ROW)
unnamed: D14.2 (A), MX14.2 (ROW)
unnamed: D15.2 (A), MX15.2 (ROW)
unnamed: D16.2 (A), MX16.2 (ROW)
unnamed: D17.2 (A), MX17.2 (ROW)
unnamed: D18.2 (A), MX18.2 (ROW)
unnamed: D19.2 (A), MX19.2 (ROW)
unnamed: D20.2 (A), MX20.2 (ROW)
unnamed: D21.2 (A), MX21.2 (ROW)
unnamed: D22.2 (A), MX22.2 (ROW)
unnamed: D23.2 (A), MX23.2 (ROW)
unnamed: D24.2 (A), MX24.2 (ROW)
unnamed: D25.2 (A), MX25.2 (ROW)
unnamed: D26.2 (A), MX26.2 (ROW)
unnamed: D27.2 (A), MX27.2 (ROW)
unnamed: D28.2 (A), MX28.2 (ROW)
unnamed: D29.2 (A), MX29.2 (ROW)
unnamed: D30.2 (A), MX30.2 (ROW)
unnamed: D31.2 (A), MX31.2 (ROW)
unnamed: D32.2 (A), MX32.2 (ROW)
unnamed: D33.2 (A), MX33.2 (ROW)
unnamed: D34.2 (A), MX34.2 (ROW)
unnamed: D35.2 (A), MX35.2 (ROW)
unnamed: D36.2 (A), MX36.2 (ROW)
unnamed: D37.2 (A), MX37.2 (ROW)
unnamed: D38.2 (A), MX38.2 (ROW)
unnamed: D39.2 (A), MX39.2 (ROW)
unnamed: D40.2 (A), MX40.2 (ROW)
unnamed: D41.2 (A), MX41.2 (ROW)
unnamed: D42.2 (A), MX42.2 (ROW)
unnamed: D43.2 (A), MX43.2 (ROW)
unnamed: D44.2 (A), MX44.2 (ROW)
unnamed: D45.2 (A), MX45.2 (ROW)
unnamed: D46.2 (A), MX46.2 (ROW)
unnamed: D47.2 (A), MX47.2 (ROW)
unnamed: D48.2 (A), MX48.2 (ROW)
unnamed: D49.2 (A), MX49.2 (ROW)
unnamed: D50.2 (A), MX50.2 (ROW)
unnamed: D51.2 (A), MX51.2 (ROW)
unnamed: D52.2 (A), MX52.2 (ROW)
unnamed: D53.2 (A), MX53.2 (ROW)
unnamed: D54.2 (A), MX54.2 (ROW)
unnamed: D55.2 (A), MX55.2 (ROW)
unnamed: D56.2 (A), MX56.2 (ROW)
unnamed: D57.2 (A), MX57.2 (ROW)
unnamed: D58.2 (A), MX58.2 (ROW)
unnamed: D59.2 (A), MX59.2 (ROW)
unnamed: D60.2 (A), MX60.2 (ROW)
unnamed: D61.2 (A), MX61.2 (ROW)
unnamed: D62.2 (A), MX62.2 (ROW)
unnamed: D63.2 (A), MX63.2 (ROW)
unnamed: D64.2 (A), MX64.2 (ROW)
unnamed: D65.2 (A), MX65.2 (ROW)
unnamed: D66.2 (A), MX66.2 (ROW)
unnamed: D67.2 (A), MX67.2 (ROW)
unnamed: D68.2 (A), MX68.2 (ROW)
unnamed: D69.2 (A), MX69.2 (ROW)
unnamed: D70.2 (A), MX70.2 (ROW)
unnamed: D71.2 (A), MX71.2 (ROW)
unnamed: D72.2 (A), MX72.2 (ROW)
unnamed: D73.2 (A), MX73.2 (ROW)
unnamed: D74.2 (A), MX74.2 (ROW)
unnamed: D75.2 (A), MX75.2 (ROW)
unnamed: D76.2 (A), MX76.2 (ROW)
unnamed: D77.2 (A), MX77.2 (ROW)
unnamed: D78.2 (A), MX78.2 (ROW)
unnamed: D79.2 (A), MX79.2 (ROW)
unnamed: D80.2 (A), MX80.2 (ROW)
unnamed: D81.2 (A), MX81.2 (ROW)
unnamed: D82.2 (A), MX82.2 (ROW)
unnamed: D83.2 (A), MX83.2 (ROW)
unnamed: D84.2 (A), MX84.2 (ROW)
unnamed: D85.2 (A), MX85.2 (ROW)
unnamed: D86.2 (A), MX86.2 (ROW)
unnamed: D87.2 (A), MX87.2 (ROW)
unnamed: D88.2 (A), MX88.2 (ROW)
unnamed: D89.2 (A), MX89.2 (ROW)
unnamed: D90.2 (A), MX90.2 (ROW)
unnamed: D91.2 (A), MX91.2 (ROW)
unnamed: D92.2 (A), MX92.2 (ROW)
unnamed: D93.2 (A), MX93.2 (ROW)
unnamed: D94.2 (A), MX94.2 (ROW)
unnamed: D95.2 (A), MX95.2 (ROW)
unnamed: D96.2 (A), MX96.2 (ROW)
unnamed: D97.2 (A), MX97.2 (ROW)
unnamed: D98.2 (A), MX98.2 (ROW)
unnamed: D99.2 (A), MX99.2 (ROW)
unnamed: D100.2 (A), MX100.2 (ROW)
unnamed: D101.2 (A), MX101.2 (ROW)
unnamed: D102.2 (A), MX102.2 (ROW)
unnamed: D103.2 (A), MX103.2 (ROW)
unnamed: D104.2 (A), MX104.2 (ROW)
unnamed: D105.2 (A), MX105.2 (ROW)
unnamed: D106.2 (A), MX106.2 (ROW)
unnamed: D107.2 (A), MX107.2 (ROW)
unnamed: D108.2 (A), MX108.2 (ROW)
unnamed: D109.2 (A), MX109.2 (ROW)
unnamed: D110.2 (A), MX110.2 (ROW)
unnamed: D111.2 (A), MX111.2 (ROW)
unnamed: D112.2 (A), MX112.2 (ROW)
unnamed: D113.2 (A), MX113.2 (ROW)
unnamed: D114.2 (A), MX114.2 (ROW)
unnamed: D115.2 (A), MX115.2 (ROW)
unnamed: D116.2 (A), MX116.2 (ROW)
unnamed: D117.2 (A), MX117.2 (ROW)
unnamed: D118.2 (A), MX118.2 (ROW)
unnamed: D119.2 (A), MX119.2 (ROW)
unnamed: D120.2 (A), MX120.2 (ROW)
unnamed: D121.2 (A), MX121.2 (ROW)
unnamed: D122.2 (A), MX122.2 (ROW)
unnamed: D123.2 (A), MX123.2 (ROW)
unnamed: D124.2 (A), MX124.2 (ROW)
unnamed: D125.2 (A), MX125.2 (ROW)
unnamed: D126.2 (A), MX126.2 (ROW)
unnamed: D127.2 (A), MX127.2 (ROW)
unnamed: D128.2 (A), MX128.2 (ROW)
col0: MX1.1 (COL), MX38.1 (COL), MX59.1 (COL), MX80.1 (COL), MX100.1 (COL), MX117.1 (COL); also elsewhere on the board
col1: MX39.1 (COL), MX60.1 (COL), MX81.1 (COL), MX101.1 (COL); also elsewhere on the board
col2: MX2.1 (COL), MX20.1 (COL), MX40.1 (COL), MX61.1 (COL), MX82.1 (COL), MX102.1 (COL), MX118.1 (COL); also elsewhere on the board
col3: MX3.1 (COL), MX21.1 (COL), MX41.1 (COL), MX62.1 (COL), MX83.1 (COL), MX103.1 (COL); also elsewhere on the board
col4: MX4.1 (COL), MX22.1 (COL), MX42.1 (COL), MX63.1 (COL), MX84.1 (COL), MX104.1 (COL), MX119.1 (COL); also elsewhere on the board
col5: MX5.1 (COL), MX23.1 (COL), MX43.1 (COL), MX64.1 (COL), MX85.1 (COL), MX105.1 (COL), MX120.1 (COL); also elsewhere on the board
col6: MX6.1 (COL), MX24.1 (COL), MX44.1 (COL), MX65.1 (COL), MX86.1 (COL), MX106.1 (COL), MX121.1 (COL); also elsewhere on the board
col7: MX7.1 (COL), MX25.1 (COL), MX45.1 (COL), MX66.1 (COL), MX87.1 (COL), MX107.1 (COL), MX122.1 (COL); also elsewhere on the board
col8: MX8.1 (COL), MX26.1 (COL), MX46.1 (COL), MX67.1 (COL), MX88.1 (COL), MX108.1 (COL); also elsewhere on the board
col9: MX9.1 (COL), MX27.1 (COL), MX47.1 (COL), MX68.1 (COL), MX89.1 (COL), MX109.1 (COL); also elsewhere on the board
col10: MX10.1 (COL), MX28.1 (COL), MX48.1 (COL), MX69.1 (COL), MX90.1 (COL), MX110.1 (COL), MX123.1 (COL); also elsewhere on the board
col11: MX11.1 (COL), MX29.1 (COL), MX49.1 (COL), MX70.1 (COL), MX91.1 (COL), MX111.1 (COL); also elsewhere on the board
col12: MX12.1 (COL), MX30.1 (COL), MX50.1 (COL), MX71.1 (COL), MX92.1 (COL), MX112.1 (COL); also elsewhere on the board
col13: MX13.1 (COL), MX31.1 (COL), MX51.1 (COL), MX72.1 (COL), MX93.1 (COL), MX113.1 (COL), MX124.1 (COL); also elsewhere on the board
col14: MX14.1 (COL), MX32.1 (COL), MX52.1 (COL), MX73.1 (COL), MX94.1 (COL), MX114.1 (COL); also elsewhere on the board
col15: MX15.1 (COL), MX33.1 (COL), MX53.1 (COL), MX74.1 (COL), MX95.1 (COL), MX115.1 (COL), MX125.1 (COL); also elsewhere on the board
col16: MX16.1 (COL), MX34.1 (COL), MX54.1 (COL), MX75.1 (COL), MX96.1 (COL); also elsewhere on the board
col17: MX17.1 (COL), MX35.1 (COL), MX55.1 (COL), MX76.1 (COL); also elsewhere on the board
col18: MX18.1 (COL), MX36.1 (COL), MX56.1 (COL), MX77.1 (COL), MX97.1 (COL), MX116.1 (COL), MX126.1 (COL); also elsewhere on the board
col19: MX19.1 (COL), MX37.1 (COL), MX57.1 (COL), MX78.1 (COL), MX98.1 (COL), MX127.1 (COL); also elsewhere on the board
col20: MX58.1 (COL), MX79.1 (COL), MX99.1 (COL), MX128.1 (COL); also elsewhere on the board
row0: D1.1 (K), D2.1 (K), D3.1 (K), D4.1 (K), D5.1 (K), D6.1 (K), D7.1 (K), D8.1 (K), D9.1 (K), D10.1 (K), D11.1 (K), D12.1 (K), D13.1 (K), D14.1 (K), D15.1 (K), D16.1 (K), D17.1 (K), D18.1 (K), D19.1 (K); also elsewhere on the board
row1: D20.1 (K), D21.1 (K), D22.1 (K), D23.1 (K), D24.1 (K), D25.1 (K), D26.1 (K), D27.1 (K), D28.1 (K), D29.1 (K), D30.1 (K), D31.1 (K), D32.1 (K), D33.1 (K), D34.1 (K), D35.1 (K), D36.1 (K), D37.1 (K); also elsewhere on the board
row2: D38.1 (K), D39.1 (K), D40.1 (K), D41.1 (K), D42.1 (K), D43.1 (K), D44.1 (K), D45.1 (K), D46.1 (K), D47.1 (K), D48.1 (K), D49.1 (K), D50.1 (K), D51.1 (K), D52.1 (K), D53.1 (K), D54.1 (K), D55.1 (K), D56.1 (K), D57.1 (K), D58.1 (K); also elsewhere on the board
row3: D59.1 (K), D60.1 (K), D61.1 (K), D62.1 (K), D63.1 (K), D64.1 (K), D65.1 (K), D66.1 (K), D67.1 (K), D68.1 (K), D69.1 (K), D70.1 (K), D71.1 (K), D72.1 (K), D73.1 (K), D74.1 (K), D75.1 (K), D76.1 (K), D77.1 (K), D78.1 (K), D79.1 (K); also elsewhere on the board
row4: D80.1 (K), D81.1 (K), D82.1 (K), D83.1 (K), D84.1 (K), D85.1 (K), D86.1 (K), D87.1 (K), D88.1 (K), D89.1 (K), D90.1 (K), D91.1 (K), D92.1 (K), D93.1 (K), D94.1 (K), D95.1 (K), D96.1 (K), D97.1 (K), D98.1 (K), D99.1 (K); also elsewhere on the board
row5: D100.1 (K), D101.1 (K), D102.1 (K), D103.1 (K), D104.1 (K), D105.1 (K), D106.1 (K), D107.1 (K), D108.1 (K), D109.1 (K), D110.1 (K), D111.1 (K), D112.1 (K), D113.1 (K), D114.1 (K), D115.1 (K), D116.1 (K); also elsewhere on the board
row6: D117.1 (K), D118.1 (K), D119.1 (K), D120.1 (K), D121.1 (K), D122.1 (K), D123.1 (K), D124.1 (K), D125.1 (K), D126.1 (K), D127.1 (K), D128.1 (K); also elsewhere on the board

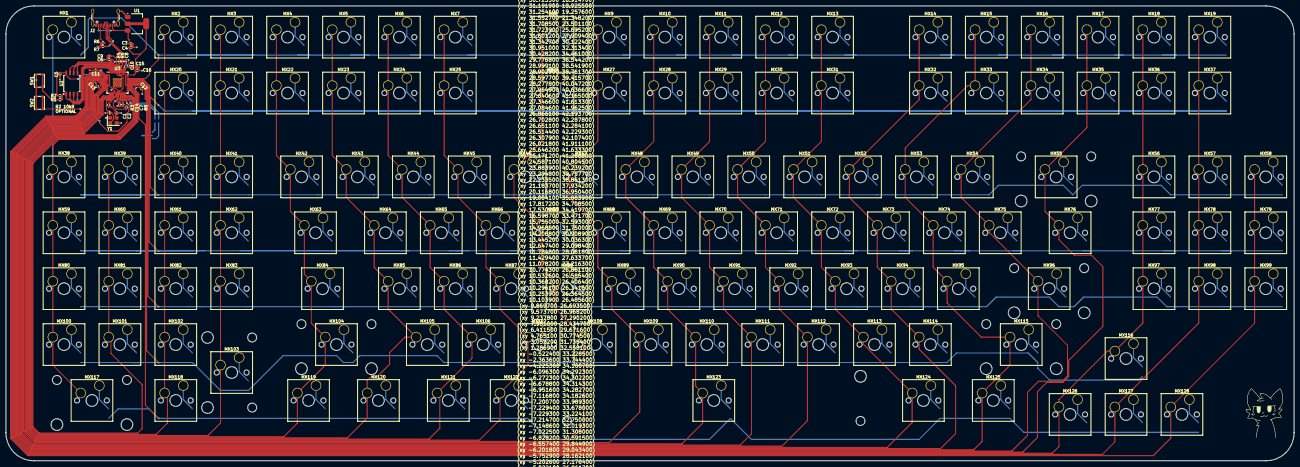
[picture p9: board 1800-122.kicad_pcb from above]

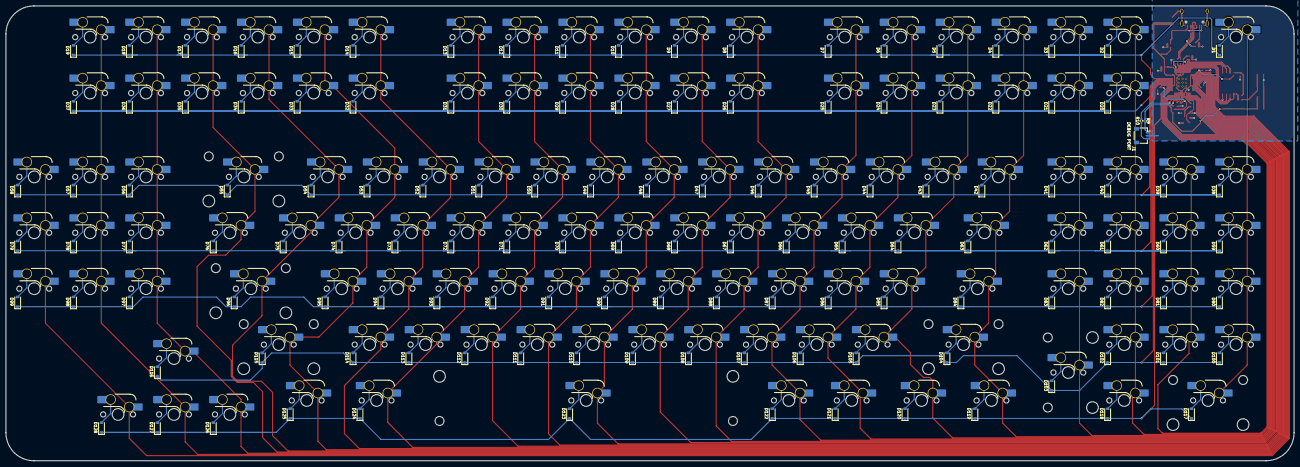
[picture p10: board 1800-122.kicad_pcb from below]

Board: 2 copper layers, 439.0 x 155.0 mm, 290 parts (131 on the bottom side), 181 nets.

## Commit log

2026-09-06 Added updated KiCAD files with local repos
    [1800122-V2.kicad_pcb, 1800122-V2.kicad_sch, switch-matrix.kicad_sch]
2026-09-08 Added updated files
    [1800122-V2.kicad_pcb, 1800122-V2.kicad_sch, switch-matrix.kicad_sch]
2026-09-08 Updated heirarchial sheet to local ref.
    [1800122-V2.kicad_pcb, 1800122-V2.kicad_sch, switch-matrix.kicad_sch]
2026-09-08 actually fixed heirarchial sheet
    [1800122-V2.kicad_pcb, 1800122-V2.kicad_sch]
2026-09-08 Fixes + new files
    Added RP2040 docs, fixed diodes in key matrix schematic, assigned RP2040 footprint to KiCAD stock QFN-56 7x7 package and made the BOOTSEL and RESET buttons smaller format.
    [1800122-V2.kicad_pcb, 1800122-V2.kicad_sch, switch-matrix.kicad_sch]
2026-09-09 Updated KiCAD layout
    [1800122-V2.kicad_pcb, 1800122-V2.kicad_sch]
2026-09-11 Added PnP for plated thru holes + literature
    [1800122-V2.kicad_pcb, 1800122-V2.kicad_sch, switch-matrix.kicad_sch]
2026-09-15 Added files
    Made changes to schematic to use unified daughter board S1 layout
    [0781710004.stp, 1800122-V2.kicad_pcb, 1800122-V2.kicad_sch]
2026-09-16 New library updates and changes to PnP footprints
    [1800122-V2.kicad_pcb, kbplacer-preset.kicad_pcb]
2026-09-26 Updated KiCad Files
    [1800122-V2.kicad_pcb, 1800122-V2.kicad_sch, switch-matrix.kicad_sch]
